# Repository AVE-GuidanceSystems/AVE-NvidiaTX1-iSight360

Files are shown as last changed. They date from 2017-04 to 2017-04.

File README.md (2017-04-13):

# AVE-NvidiaTX1-iSight360
GPIO Breakout for iSight360

# Purpose
This PCB layout is intended to be for prototype purposes. This board fundamentally breaks out GPIO that is necessary for the iSight360 danger avoidence unit. Current build is limited to the layout and footprint size of the Development Carrier board provided by the Nvidia Jetson TX1. Future builds will include an all integrated carrier module to reduce overall footprint size.

Current build schematics are located under the PDFs folder. Schematics are found in the Schematics folder and Layout file is in the main directory along with project file and component banks.

# 3D Model
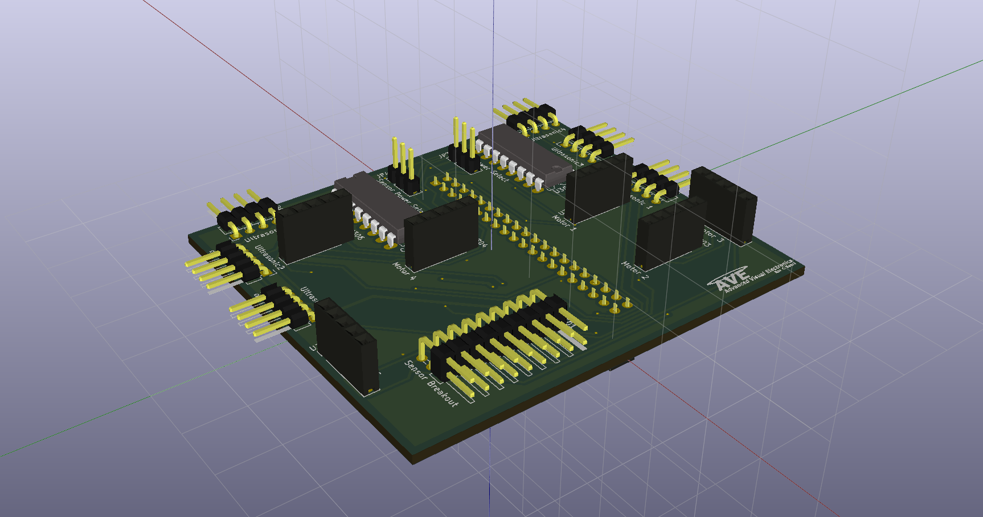
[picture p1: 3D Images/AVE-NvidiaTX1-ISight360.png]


     - All 3-D models are in the designated folder

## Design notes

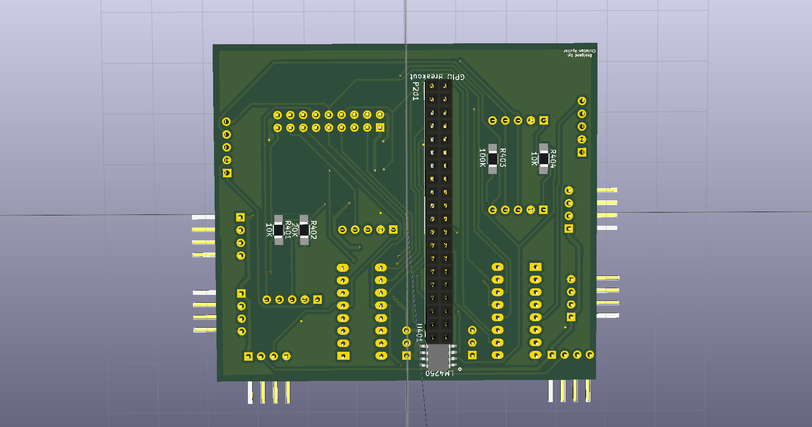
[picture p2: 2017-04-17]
3D Images/Bottom Down.png

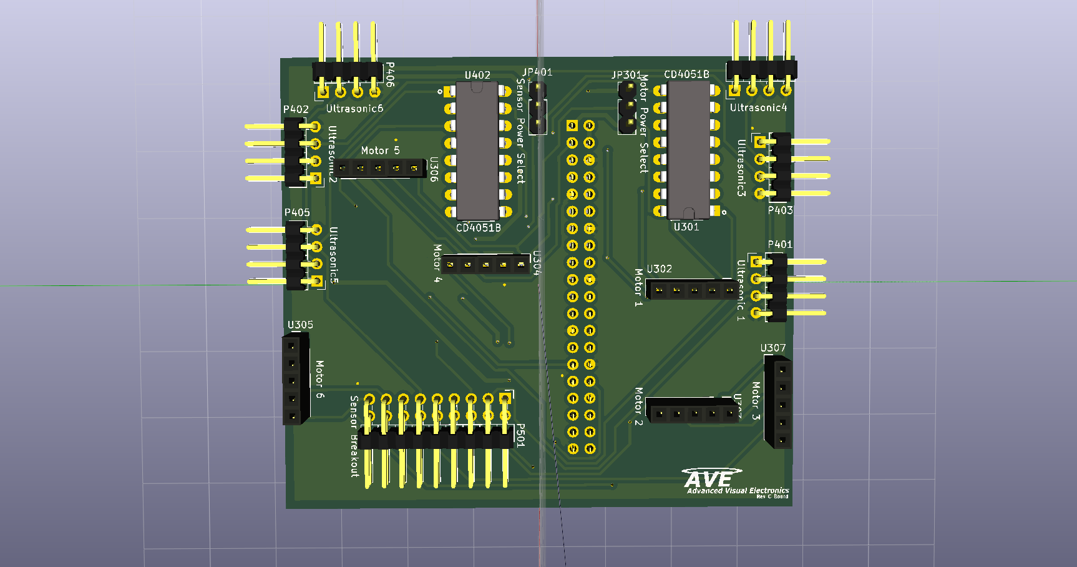
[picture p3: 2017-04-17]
3D Images/Top Down.png

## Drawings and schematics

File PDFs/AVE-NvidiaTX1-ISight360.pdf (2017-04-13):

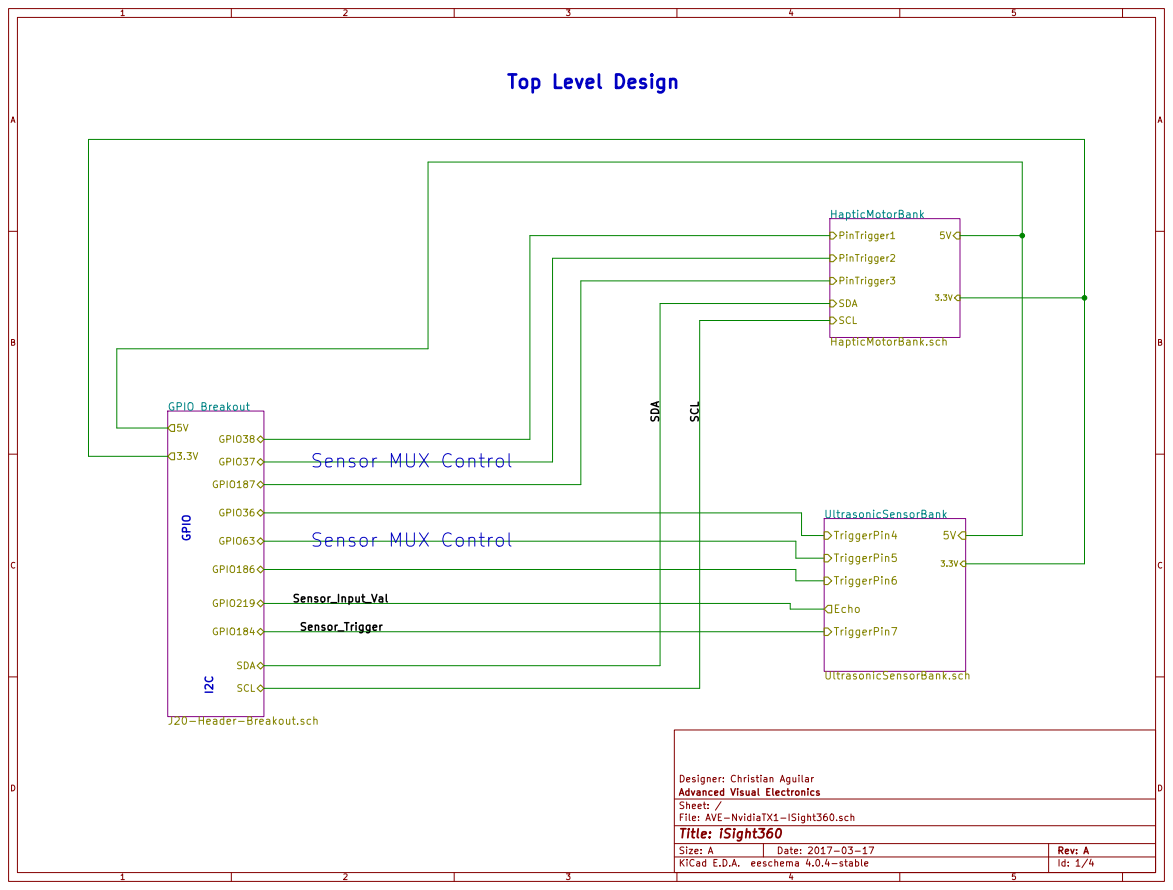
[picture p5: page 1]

File: AVE-NvidiaTX1-ISight360.sch Sheet: / Advanced Visual Electronics Designer: Christian Aguilar

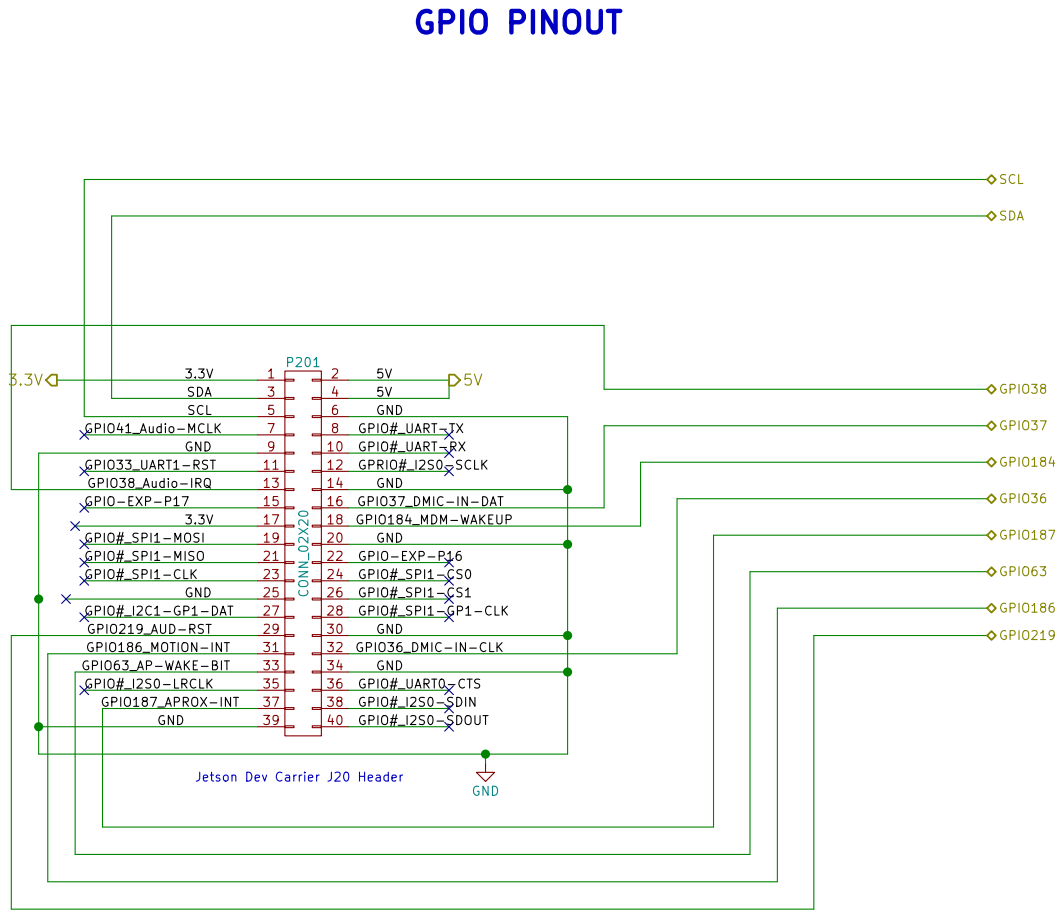
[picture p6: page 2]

GPIO#_SPI1-CLKGND GPIO#_I2C1-GP1-DAT

31 | | 32
33 | | 34
35 | | 36

Id: 2/4 Title: GPIO Breakout File: J20-Header-Breakout.sch Sheet: /GPIO Breakout/ Advanced Visual Electronics Designer: Christian Aguilar

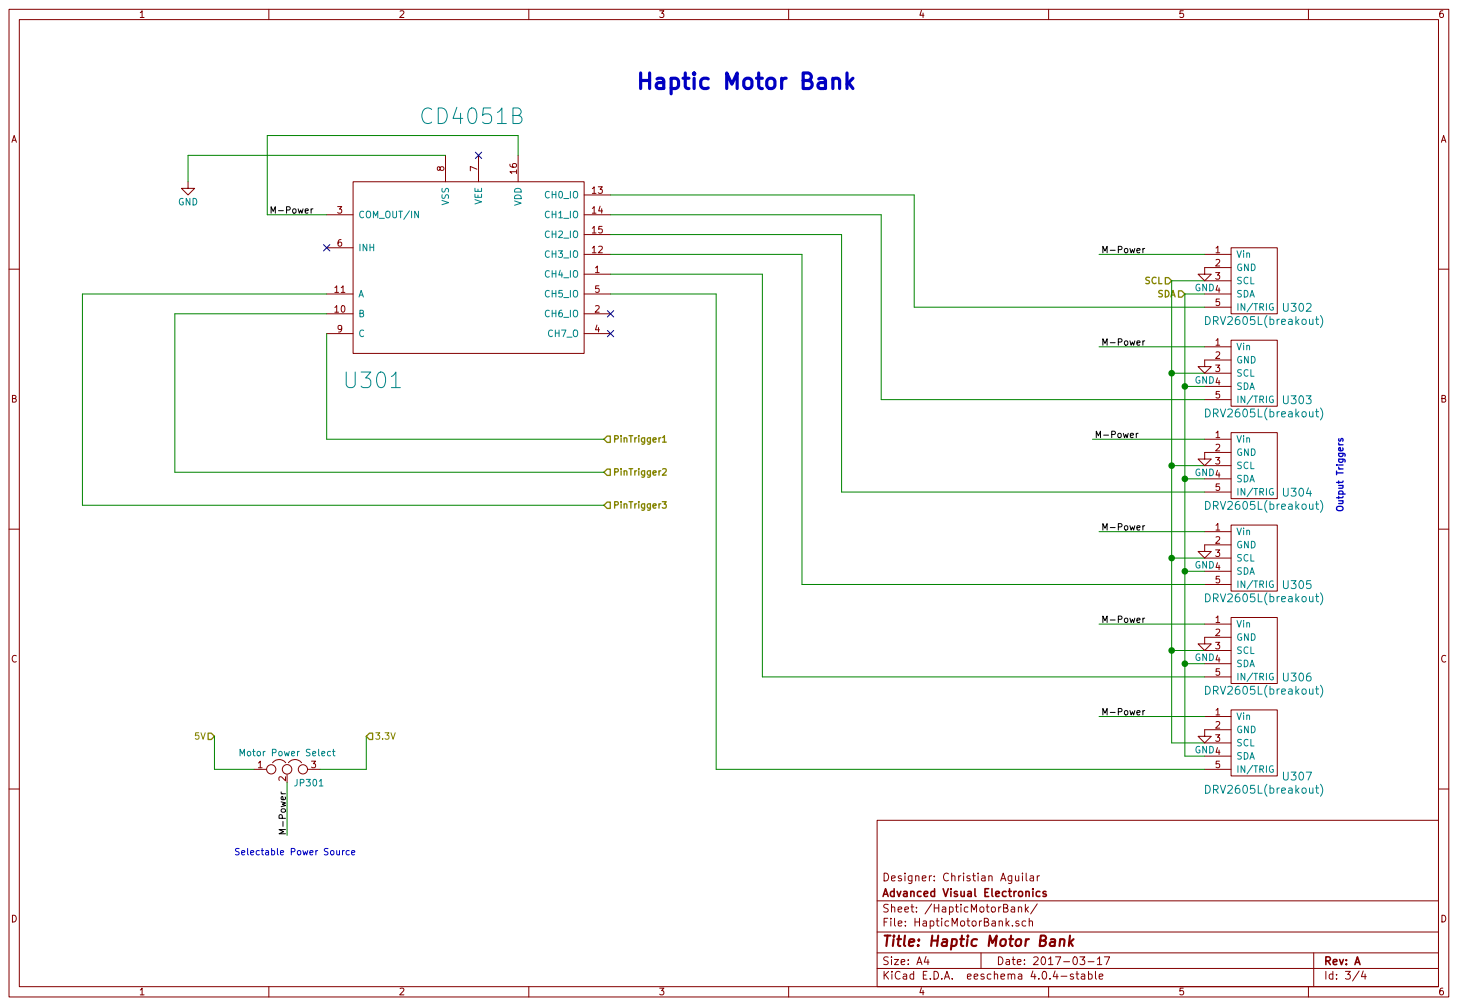
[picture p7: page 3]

M-Power M-Power M-Power M-Power M-Power M-Power M-Power

Sheet: /HapticMotorBank/ Advanced Visual Electronics Designer: Christian Aguilar

File: HapticMotorBank.sch
Id: 3/4 Title: Haptic Motor Bank

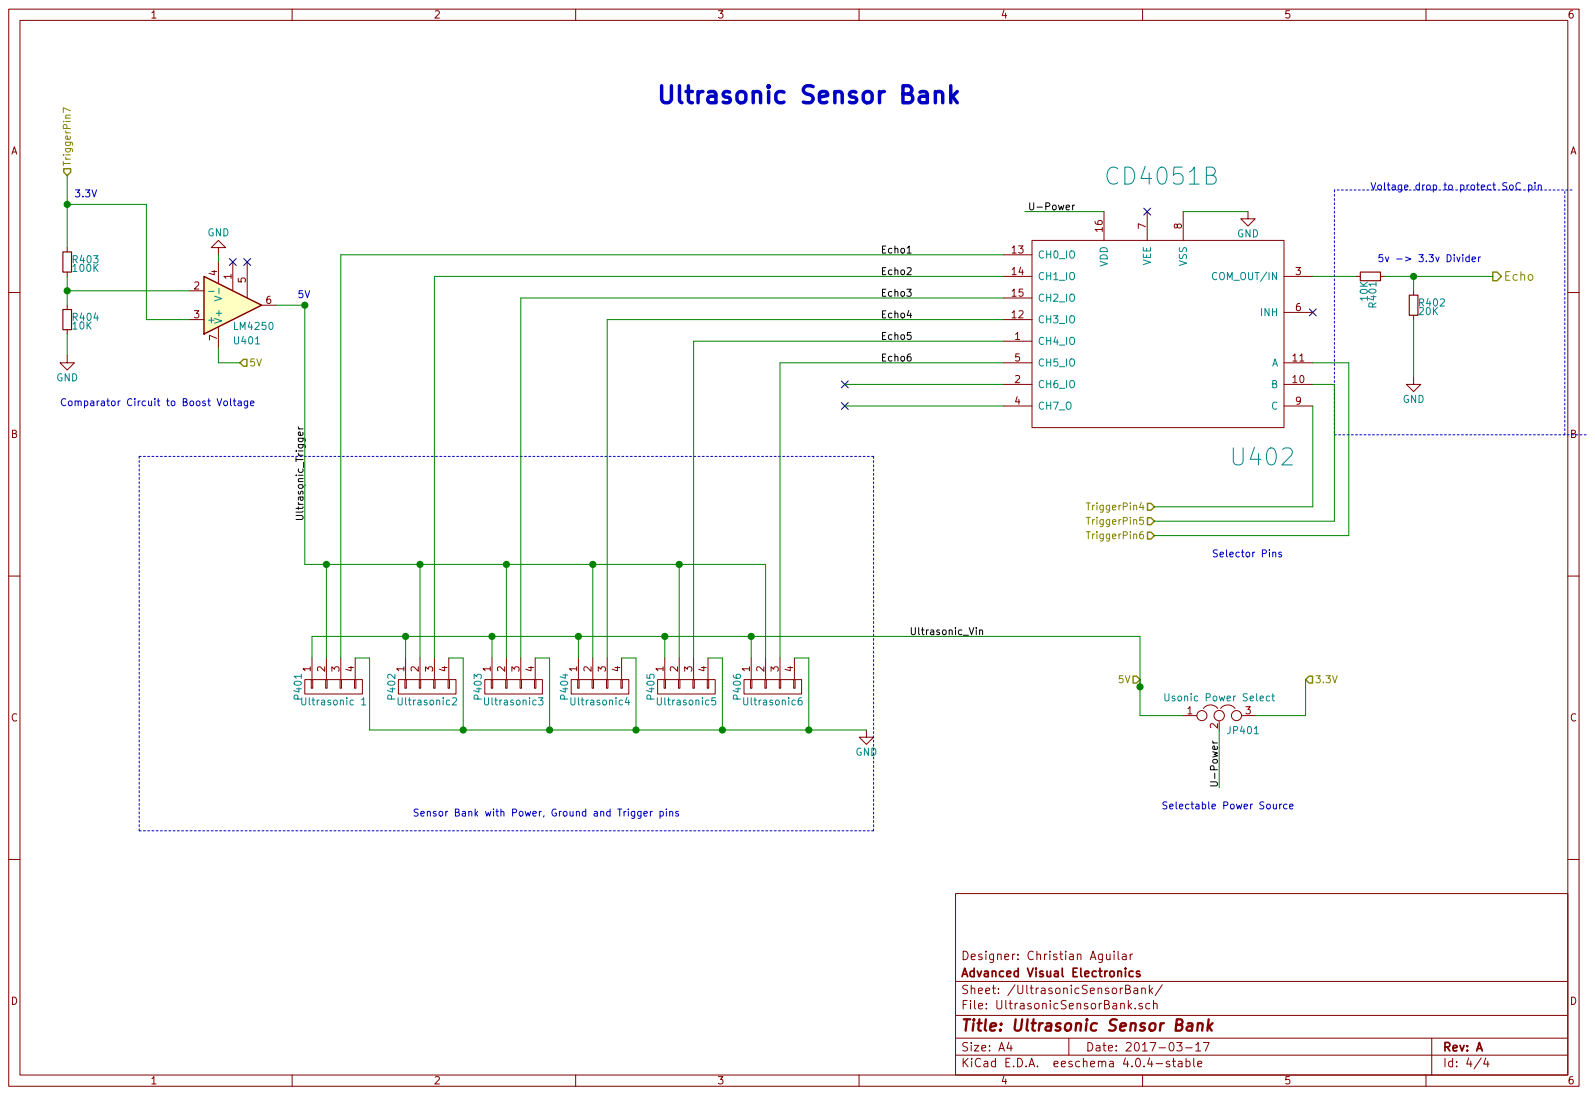
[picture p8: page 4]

Voltage drop to protect SoC pin

Comparator Circuit to Boost Voltage

Sensor Bank with Power, Ground and Trigger pins

File: UltrasonicSensorBank.sch Sheet: /UltrasonicSensorBank/ Advanced Visual Electronics Designer: Christian Aguilar

Id: 4/4 Title: Ultrasonic Sensor Bank

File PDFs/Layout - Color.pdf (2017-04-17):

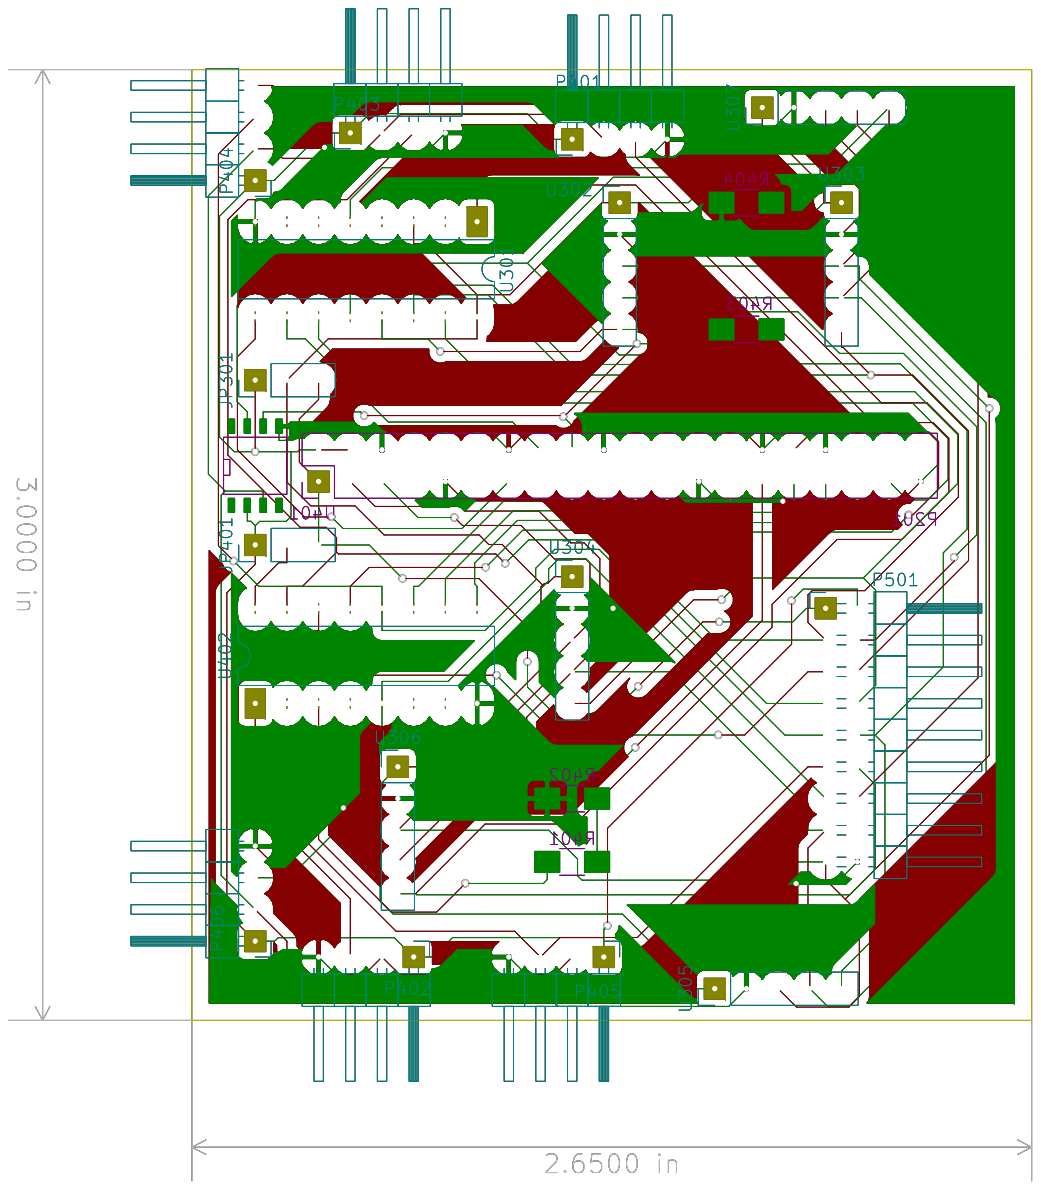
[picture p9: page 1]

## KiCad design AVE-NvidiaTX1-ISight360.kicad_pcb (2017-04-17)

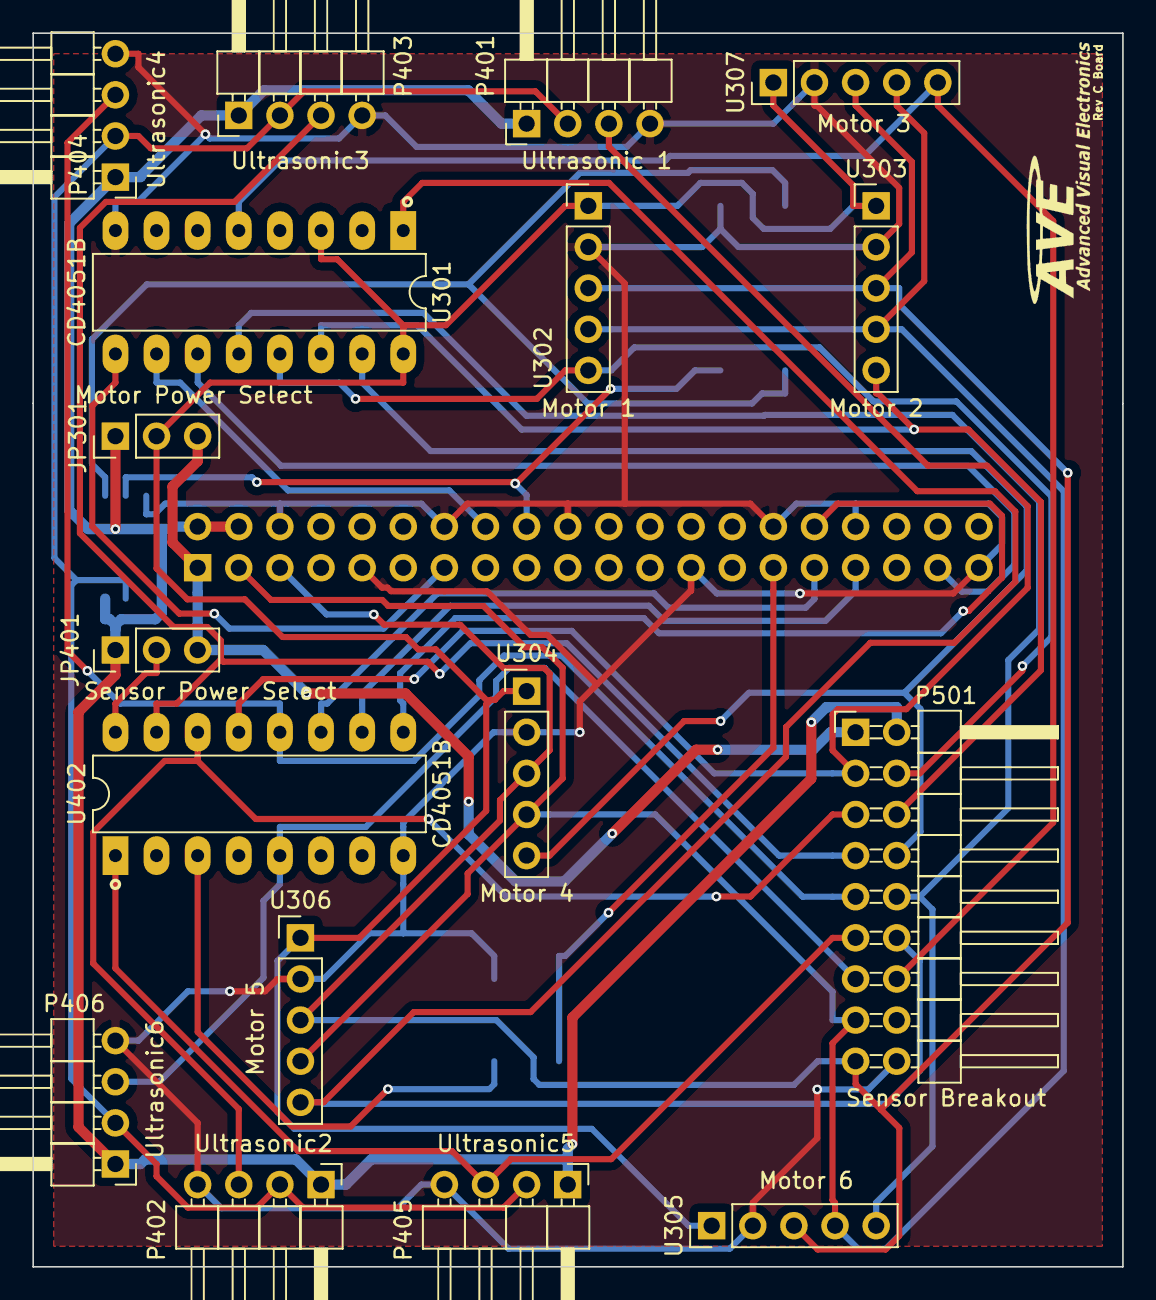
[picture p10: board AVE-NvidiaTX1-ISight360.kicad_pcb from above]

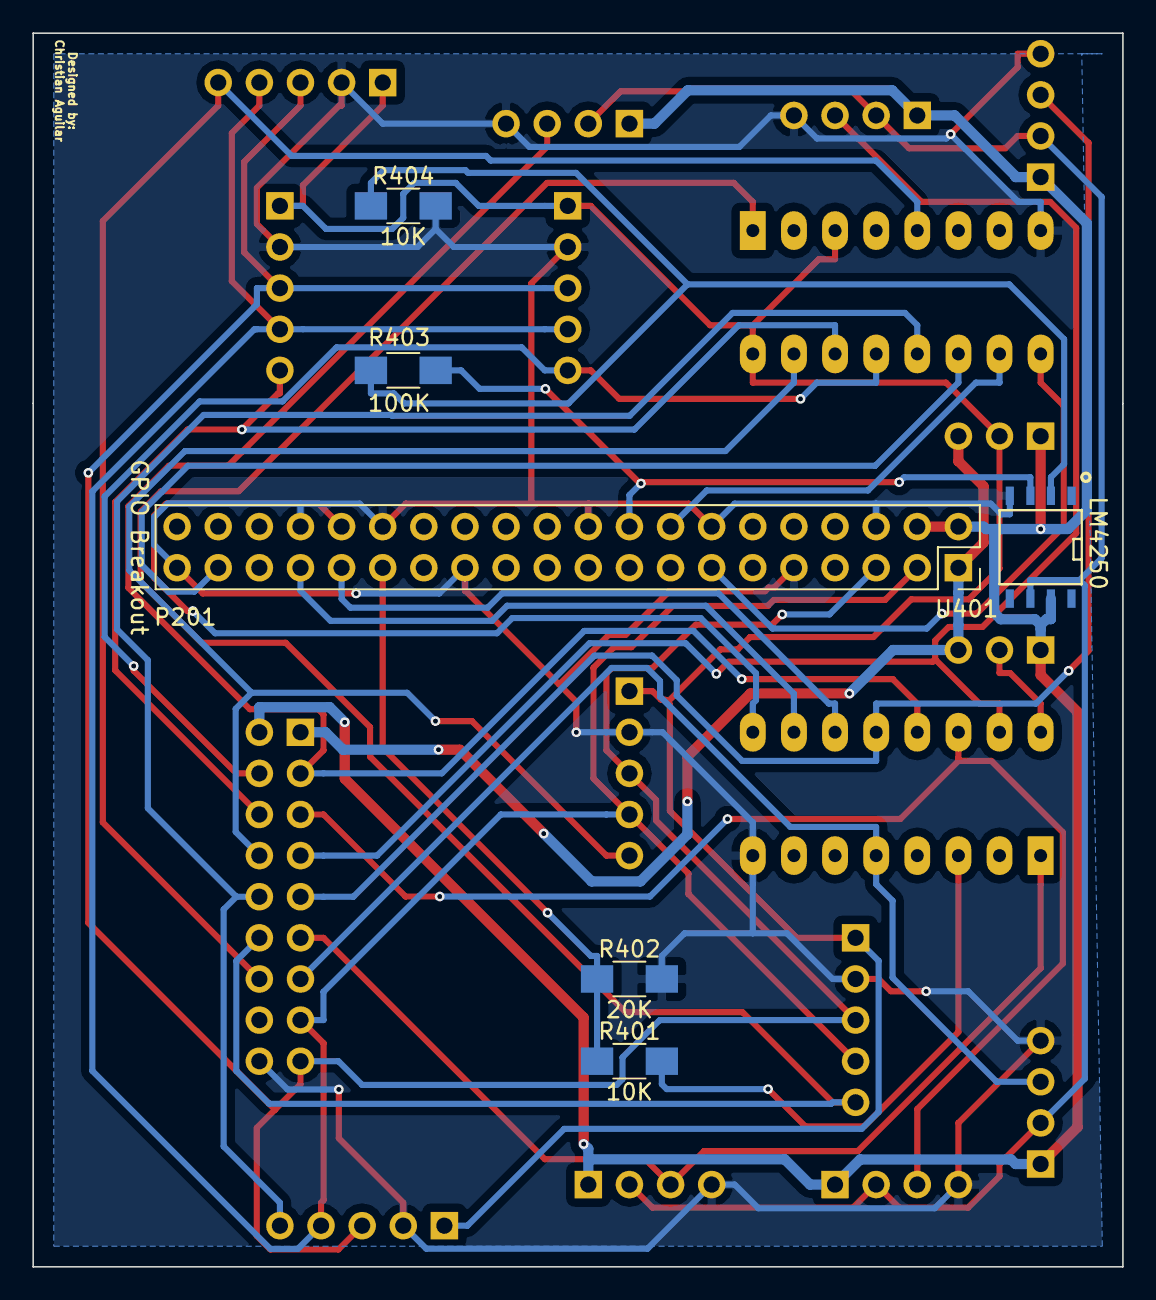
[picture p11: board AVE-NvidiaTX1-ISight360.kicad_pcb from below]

Board: 2 copper layers, 67.3 x 76.2 mm, 23 parts (6 on the bottom side), 30 nets.

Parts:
JP301: Motor Power Select; Pin_Header_Straight_1x03_Pitch2.54mm
JP401: Sensor Power Select; Pin_Header_Straight_1x03_Pitch2.54mm
P201: GPIO Breakout; Socket_Strip_Straight_2x20_Pitch2.54mm
P401: Ultrasonic 1; Pin_Header_Angled_1x04_Pitch2.54mm
P402: Ultrasonic2; Pin_Header_Angled_1x04_Pitch2.54mm
P403: Ultrasonic3; Pin_Header_Angled_1x04_Pitch2.54mm
P404: Ultrasonic4; Pin_Header_Angled_1x04_Pitch2.54mm
P405: Ultrasonic5; Pin_Header_Angled_1x04_Pitch2.54mm
P406: Ultrasonic6; Pin_Header_Angled_1x04_Pitch2.54mm
P501: Sensor Breakout; Pin_Header_Angled_2x09_Pitch2.54mm
R401, R404: 10K; R_1206_HandSoldering
R402: 20K; R_1206_HandSoldering
R403: 100K; R_1206_HandSoldering
U301, U402: CD4051B; DIP-16_W7.62mm_LongPads
U302: Motor 1; Socket_Strip_Straight_1x05_Pitch2.54mm
U303: Motor 2; Socket_Strip_Straight_1x05_Pitch2.54mm
U304: Motor 4; Socket_Strip_Straight_1x05_Pitch2.54mm
U305: Motor 6; Socket_Strip_Straight_1x05_Pitch2.54mm
U306: Motor 5; Socket_Strip_Straight_1x05_Pitch2.54mm
U307: Motor 3; Socket_Strip_Straight_1x05_Pitch2.54mm
U401: LM4250; SOIC-8-N

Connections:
/Echo1: P401.3, P501.3, U402.13
/Echo2: P402.3, P501.5, U402.14
/Echo3: P403.3, P501.7, U402.15
/Echo4: P404.3, P501.9, U402.12
/Echo5: P405.3, P501.11, U402.1
/Echo6: P406.3, P501.13, U402.5
/GPIO Breakout/3.3V: JP301.3, JP401.3, P201.1, P501.1
/GPIO Breakout/5V: JP301.1, JP401.1, P201.2, P201.4, P401.1, P402.1, P403.1, P404.1, P405.1, P406.1, P501.2, U401.7
/GPIO Breakout/GPIO36: P201.32, U402.9
/GPIO Breakout/GPIO37: P201.16, U301.10
/GPIO Breakout/GPIO38: P201.13, U301.9
/GPIO Breakout/GPIO63: P201.33, U402.10
/GPIO Breakout/GPIO186: P201.31, U402.11
/GPIO Breakout/GPIO187: P201.37, U301.11
/HapticMotorBank/M-Power: JP301.2, U301.3, U301.16, U302.1, U303.1, U304.1, U305.1, U306.1, U307.1
/Mtrigger1: P501.4, U301.13, U302.5
/Mtrigger2: P501.6, U301.14, U303.5
/Mtrigger3: P501.8, U301.15, U304.5
/Mtrigger4: P501.10, U301.12, U305.5
/Mtrigger5: P501.12, U301.1, U306.5
/Mtrigger6: P501.14, U301.5, U307.5
/SCL: P201.5, P501.17, U302.3, U303.3, U304.3, U305.3, U306.3, U307.3
/SDA: P201.3, P501.15, U302.4, U303.4, U304.4, U305.4, U306.4, U307.4
/Sensor_Input_Val: P201.29, R401.1, R402.1
/Sensor_Trigger: P201.18, R403.1, U401.3
/UltrasonicSensorBank/U-Power: JP401.2, U402.16
/UltrasonicTigger: P401.2, P402.2, P403.2, P404.2, P405.2, P406.2, U401.6
GND: P201.6, P201.9, P201.14, P201.20, P201.25, P201.30, P201.34, P201.39, P401.4, P402.4, P403.4, P404.4, P405.4, P406.4, P501.18, R402.2, R404.2, U301.8, U302.2, U303.2, U304.2, U305.2, U306.2, U307.2, U401.4, U402.8
unnamed: R401.2, U402.3
unnamed: R403.2, R404.1, U401.2

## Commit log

2017-03-16 Schematic Page Setting Updated
    [AVE-NvidiaTX1-ISight360.sch, HapticMotorBank.sch, J20-Header-Breakout.sch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]
2017-03-16 Supplied Components to Ultrasonic bank
    [AVE-NvidiaTX1-ISight360.sch, Power.sch, UltrasonicSensorBank.sch]
2017-03-16 Added Components to J20Header Breakout
    [J20-Header-Breakout.sch]
2017-03-16 Added components
    [HapticMotorBank.sch, UltrasonicSensorBank.sch]
2017-03-17 Rev 1 Schematics
    [AVE-NvidiaTX1-ISight360.sch, HapticMotorBank.sch, J20-Header-Breakout.sch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]
2017-03-17 Rev 1 - fix and PDFs
    [UltrasonicSensorBank.sch]
2017-03-31 added DRV breakout board to haptic motor bank schematic
    [HapticMotorBank.sch]
2017-04-03 More GPIO Pins Available
    [HapticMotorBank.sch, J20-Header-Breakout.sch]
2017-04-10 Rev .99999 w/ Layout
    [AVE-NvidiaTX1-ISight360.kicad_pcb, AVE-NvidiaTX1-ISight360.sch, HapticMotorBank.sch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]
2017-04-10 Rearranged Schematic Files
    [AVE-NvidiaTX1-ISight360.sch, HapticMotorBank.sch, J20-Header-Breakout.sch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]
2017-04-13 Reduced number of components
    [AVE-NvidiaTX1-ISight360.kicad_pcb, AVE-NvidiaTX1-ISight360.sch, HapticMotorBank.sch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]
2017-04-13 Layout Done
    Minor Tweaks were made to Schematic
    [AVE-NvidiaTX1-ISight360-Backup.kicad_pcb, HapticMotorBank.sch, J20-Header-Breakout.sch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]
2017-04-15 Redesign - Rev B Board
    Smaller Board, more symmetric, will be more stable
    [AVE-NvidiaTX1-ISight360-Working.dsn, AVE-NvidiaTX1-ISight360.dsn, AVE-NvidiaTX1-ISight360.kicad_pcb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]
2017-04-17 Rev C Update
    [AVE-NvidiaTX1-ISight360.dsn, AVE-NvidiaTX1-ISight360.kicad_pcb, AVE-NvidiaTX1-ISight360.sch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]
2017-04-17 Rev C Final: PDFs, 3D Images, Silkscreens all updated
    [AVE-NvidiaTX1-ISight360-B.Adhes.gbr, AVE-NvidiaTX1-ISight360-B.Cu.gbr, AVE-NvidiaTX1-ISight360-B.Mask.gbr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]
